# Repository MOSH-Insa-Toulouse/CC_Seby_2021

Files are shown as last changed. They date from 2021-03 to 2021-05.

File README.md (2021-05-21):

# Projet Capteur Graphite

Nous vous souhaitons bonne navigation dans notre GitHub ! 

# Sommaire
<!-- TOC depthFrom:2 -->
- [Projet Capteur Graphite](#projet-capteur-graphite)
- [Sommaire](#sommaire)
  - [1. Description](#1-description)
  - [2. Configuration de l'environnement logiciel](#2-configuration-de-lenvironnement-logiciel)
    - [2.1. Arduino](#21-arduino)
      - [2.1.1. Bibliothèques](#211-bibliothèques)
    - [2.2. KICAD](#22-kicad)
    - [2.3. Application Android](#23-application-android)
      - [2.3.1. Installer l'application](#231-installer-lapplication)
      - [2.3.2. Modifier l'application](#232-modifier-lapplication)
  - [3. Améliorations Possibles](#3-améliorations-possibles)
    - [3.1. Amélioration 1 : KICAD - Taille des pistes](#31-amélioration-1--kicad---taille-des-pistes)
    - [3.2. Amélioration 2 : KICAD - Taille des pastilles](#32-amélioration-2--kicad---taille-des-pastilles)
    - [3.3. Amélioration 3 : KICAD - Place du capteur](#33-amélioration-3--kicad---place-du-capteur)
    - [3.4. Amélioration 4 : KICAD - Orientation de l'encodeur rotatoire](#34-amélioration-4--kicad---orientation-de-lencodeur-rotatoire)
    - [3.5. Amélioration 5 : Arduino & Android - Économie du buffer Bluetooth](#35-amélioration-5--arduino--android---économie-du-buffer-bluetooth)
  - [4. Remerciements](#4-remerciements)
  - [5. Informations sur les auteurs](#5-informations-sur-les-auteurs)
<!-- /TOC -->

## 1. Description 

Ce Git contient tous les fichiers requis pour le projet capteur 2021 du Génie Physique de l'INSA de Toulouse.

**Code Arduino**

- Mesure la tension de sortie du circuit transimpédance
- Envoie la mesure de la tension en Bluetooth sur 1 octet
- Calcule la résistance du capteur grâce à l'équation de transfert du circuit dans la data sheet
- Affiche les mesures sur un écran oled 128x32
- Gère l'encodeur rotatoire pour interagir avec un menu sur l'écran oled

**KICAD**

Projet complet de design de shield pour Arduino Uno :

- Interface un module Bluetooth
- Interface un écran oled
- Interface notre capteur graphite via un circuit transimpédance
- Interface un encodeur rotatoire

**Application Android**

- Récupère la mesure de tension en binaire sur 1 octet
- Affiche la valeur de la tension en Volt
- Calcule la résistance du capteur grâce à l'équation de transfert du circuit dans la data sheet
- Affiche la valeur de la résistance MΩ
- Trace un graphique déroulant de la résistance du capteur
- Mise à l'échelle du graphique grâce à un slider

**Data Sheet**

- Caractéristiques principales
- Description du capteur 
- Schéma et dimensions 
- Spécifications
- Conditions d'utilisation normales
- Caractéristiques électriques
- Caractéristiques de déformation
- Montage typique d'utilisation

## 2. Configuration de l'environnement logiciel

### 2.1. Arduino

Lien pour installer l'IDE Arduino sur sa machine : https://www.arduino.cc/en/software

#### 2.1.1. Bibliothèques

À installer depuis l'IDE ou GitHub : 
- Adafruit GFX Library : https://github.com/adafruit/Adafruit-GFX-Library
- Adafruit SSD1306 : https://github.com/adafruit/Adafruit_SSD1306
- Adafruit BusIO : https://github.com/adafruit/Adafruit_BusIO

Comment installer une bibliothèque Arduino ? : https://www.arduino.cc/en/Guide/Libraries#how-to-install-a-library

### 2.2. KICAD

Lien pour installer KICAD sur sa machine : https://www.kicad.org/

### 2.3. Application Android

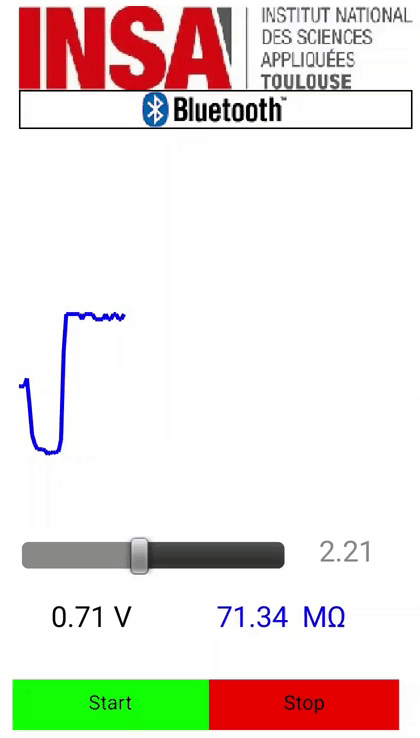
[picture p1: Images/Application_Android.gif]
Application Android


#### 2.3.1. Installer l'application

Lien pour installer un fichier .apk à partir d'un PC : https://fr.wikihow.com/installer-sur-un-Android-des-fichiers-APK-%C3%A0-partir-d%E2%80%99un-PC

#### 2.3.2. Modifier l'application

Pour modifier le code de l'application Android, vous pouvez utiliser le fichier en .aia dans MIT Inventor : https://appinventor.mit.edu/

## 3. Améliorations Possibles

### 3.1. Amélioration 1 : KICAD - Taille des pistes

À l'INSA Toulouse, la méthode d'impression du Shield par photolithographie avec du matériel rudimentaire a engendré de nombreux court-circuits entre les pistes de la plaque. Il peut-être judicieux d'augmenter la taille des pistes du PCB dans KICAD selon le matériel. **À l'INSA 0.8mm sont recommandés**

**Comment modifier la taille des pistes ?**

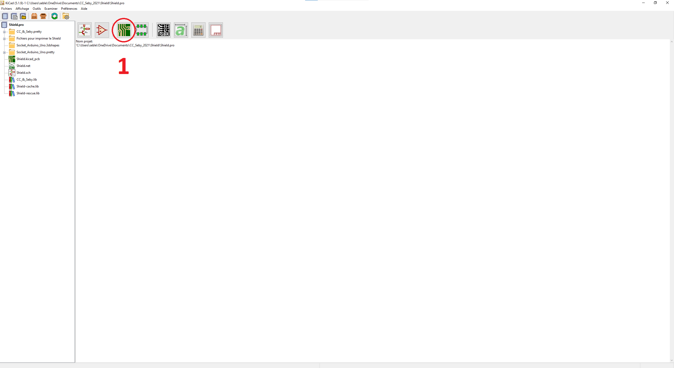
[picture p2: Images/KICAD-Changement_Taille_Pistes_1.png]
Étape 1

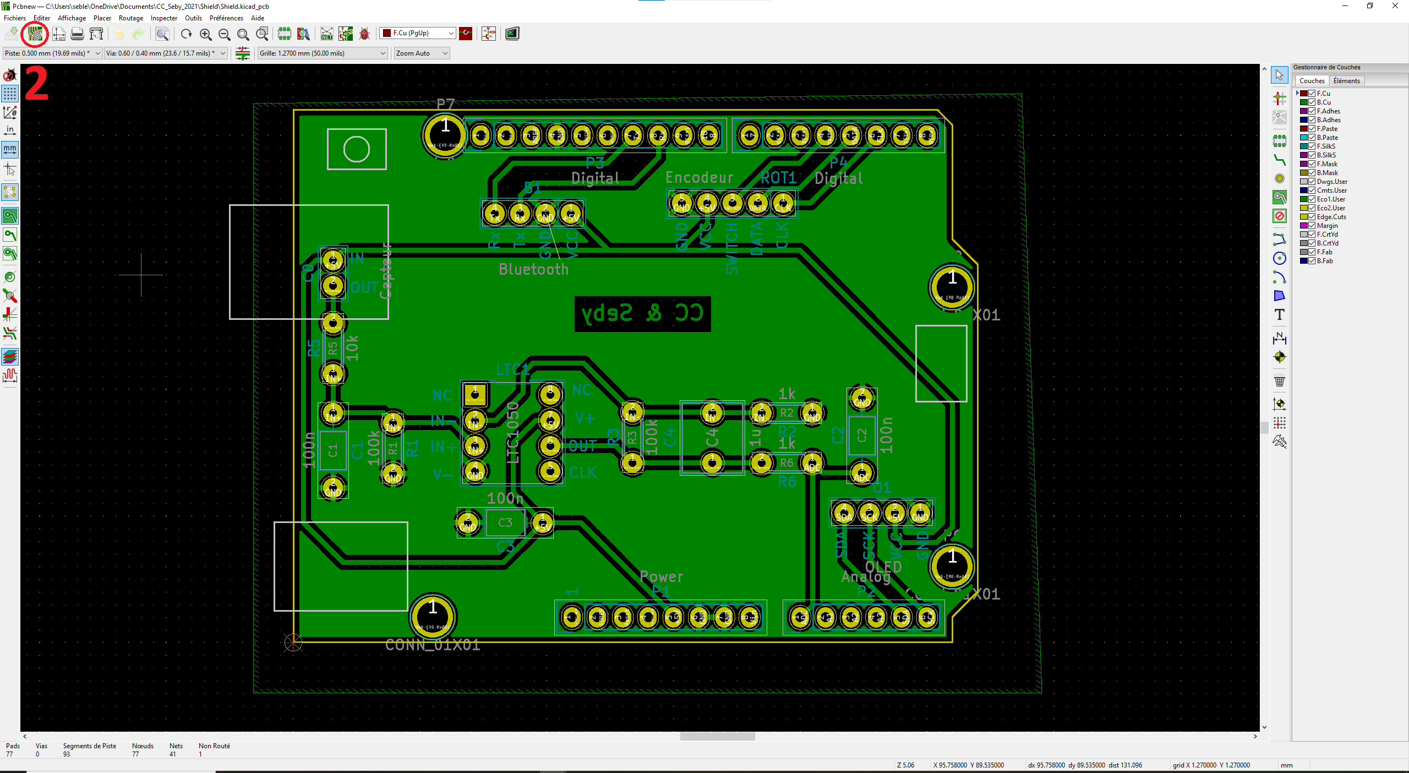
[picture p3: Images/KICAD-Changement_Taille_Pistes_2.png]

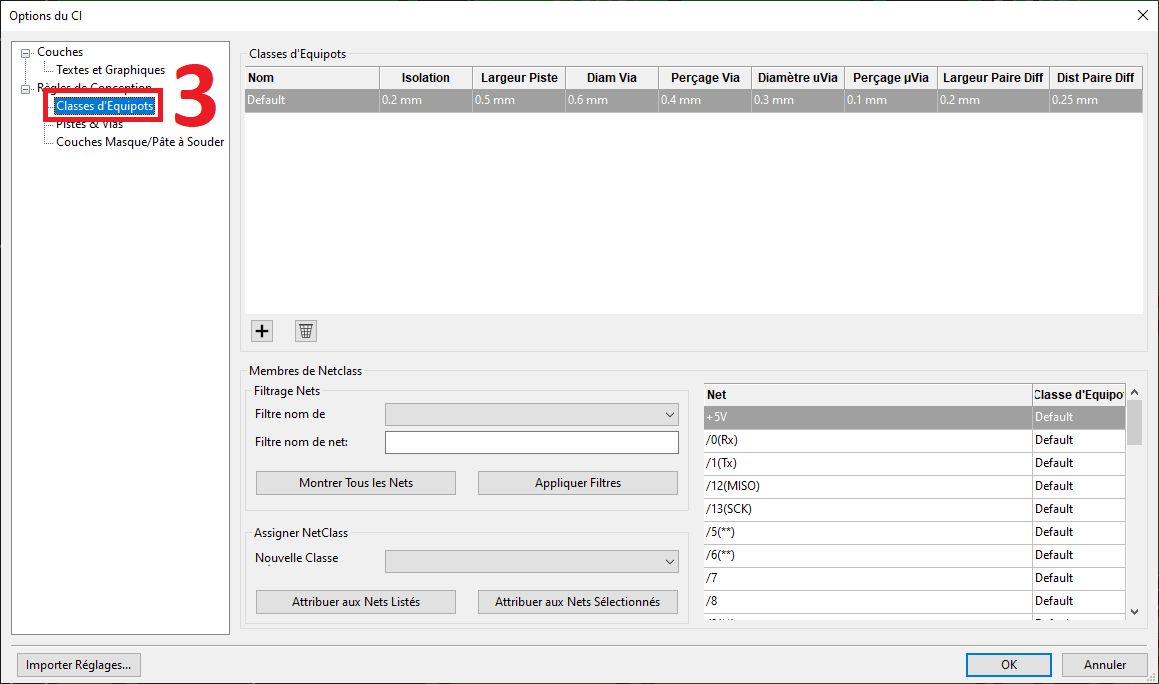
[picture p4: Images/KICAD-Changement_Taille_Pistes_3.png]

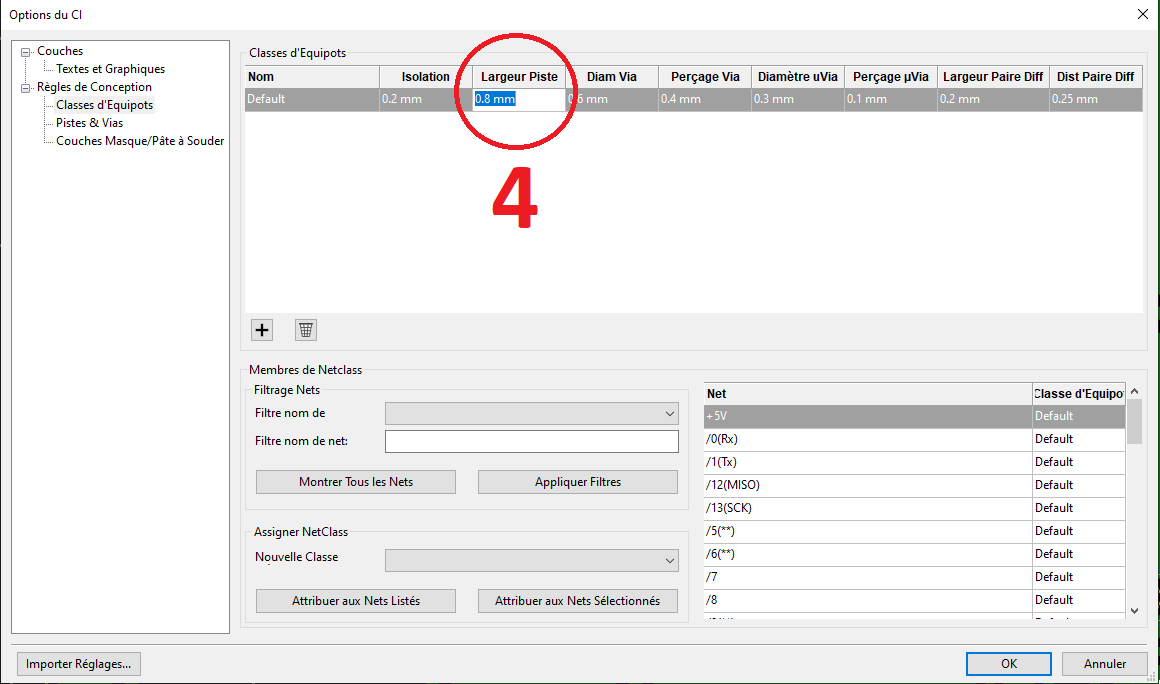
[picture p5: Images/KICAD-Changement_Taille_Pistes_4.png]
Étape 4


Il faut ensuite supprimer les pistes et refaire le routage de la carte.

### 3.2. Amélioration 2 : KICAD - Taille des pastilles

À l'INSA Toulouse, le foret de la perceuse a un diamètre de 0.8mm, il faut donc prévoir un **perçage supérieur ou égal à 0.8mm**.

Étape 1
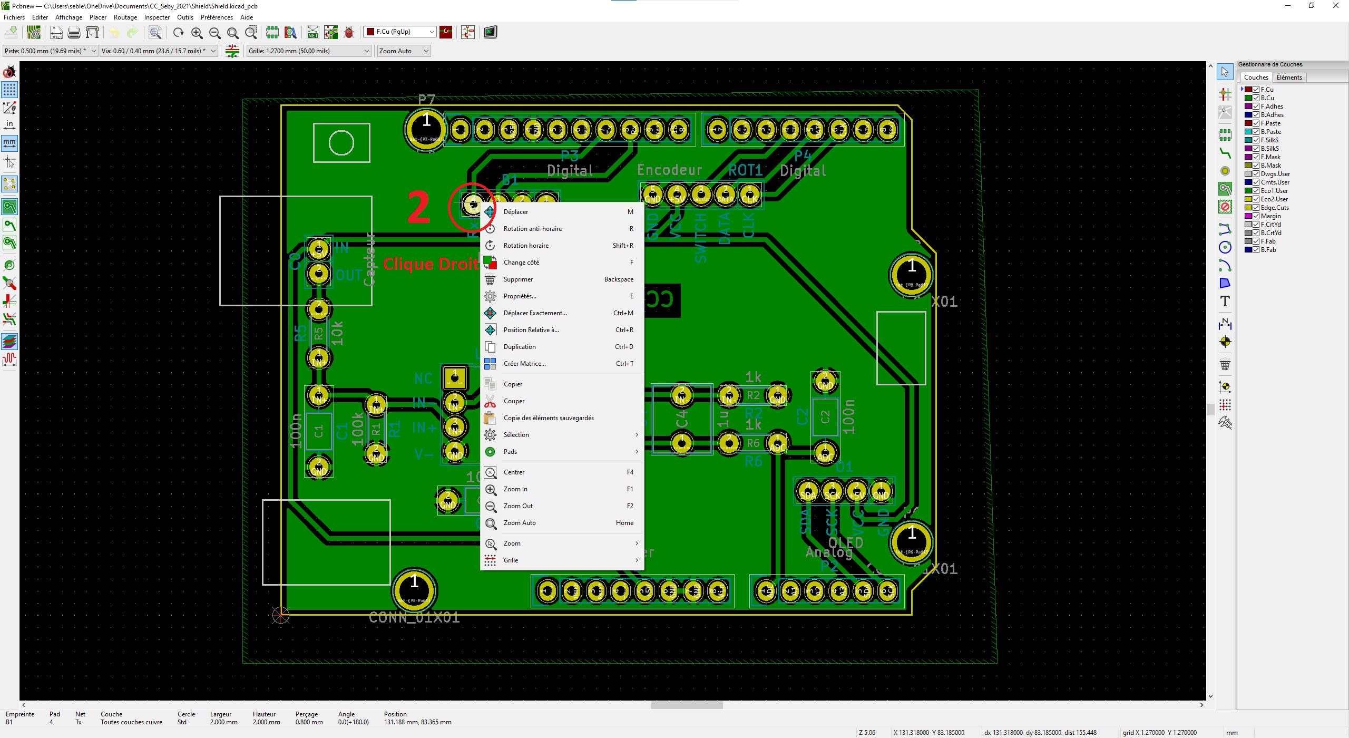
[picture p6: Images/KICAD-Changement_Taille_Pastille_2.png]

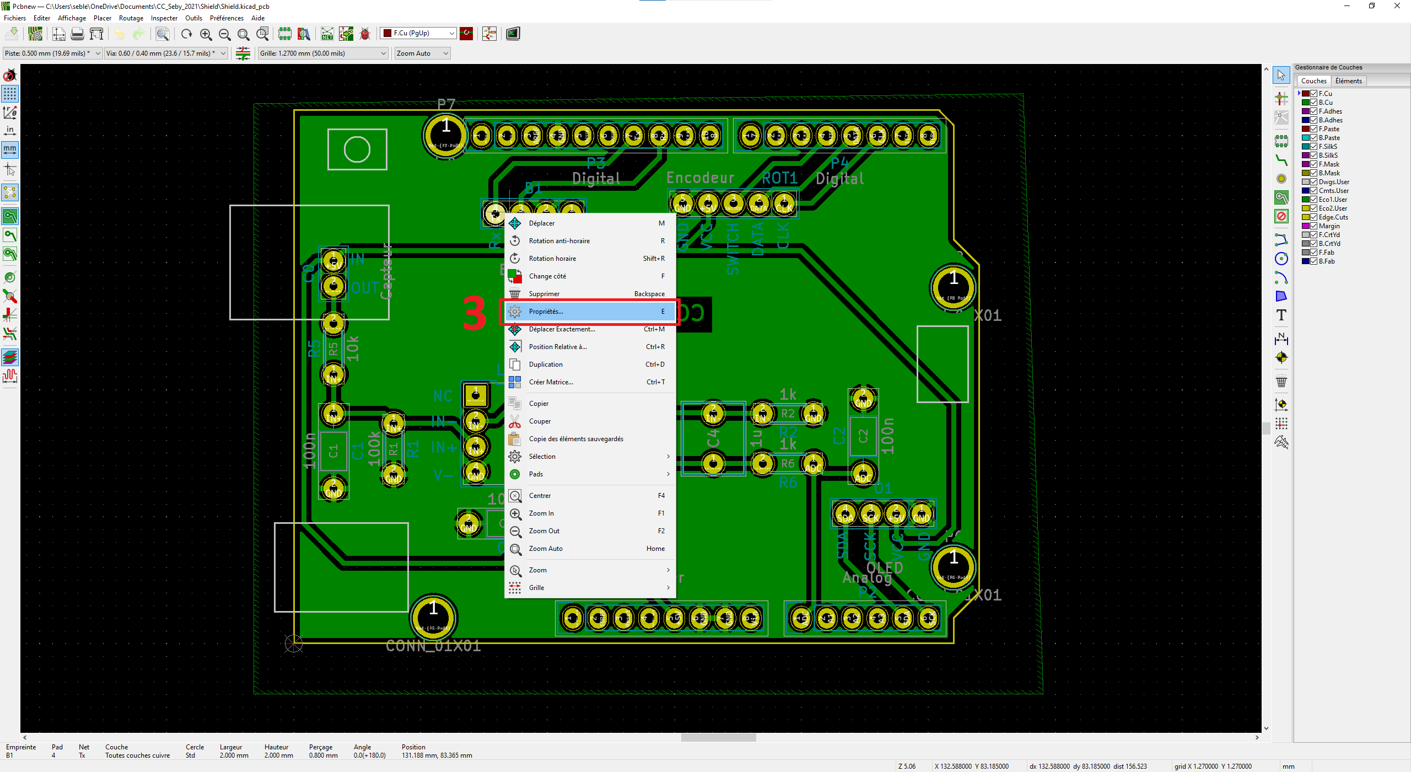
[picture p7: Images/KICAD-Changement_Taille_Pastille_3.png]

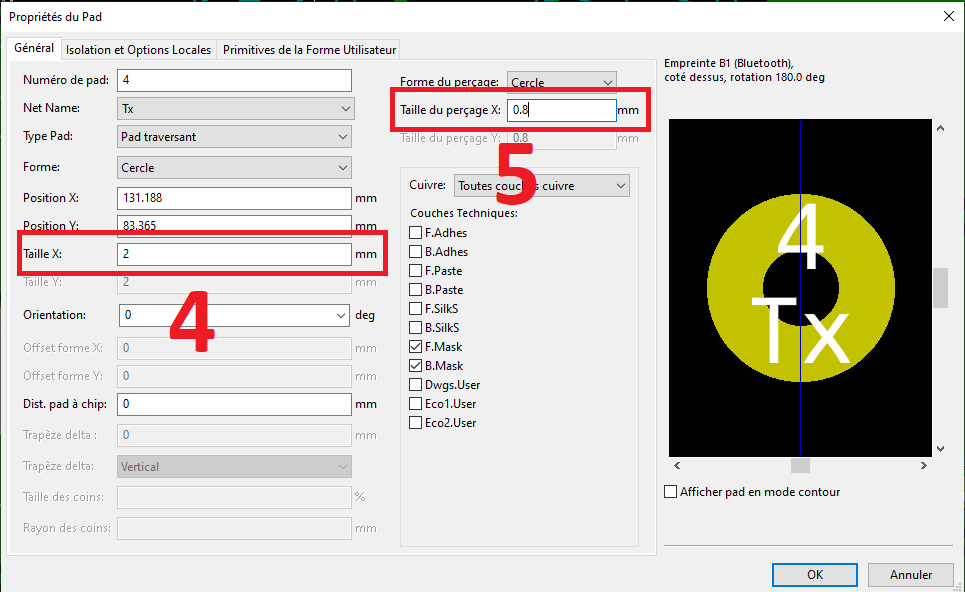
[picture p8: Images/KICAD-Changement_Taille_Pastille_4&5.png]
Étape 4&5


### 3.3. Amélioration 3 : KICAD - Place du capteur

**Description du problème**

Les pins de connexion fournis du shield à l'Arduino étant un peu courts. Les soudures des connexions du capteur sont en contact avec le boitier de blindage de l'USB qui est à la masse. Nous avons rajouté une feuille de papier entre le Shield et l'Arduino afin d'assurer l'isolation. Un changement de design du Shield serait donc judicieux avant toute nouvelle impression.

**Solution Proposée**

Étape 1
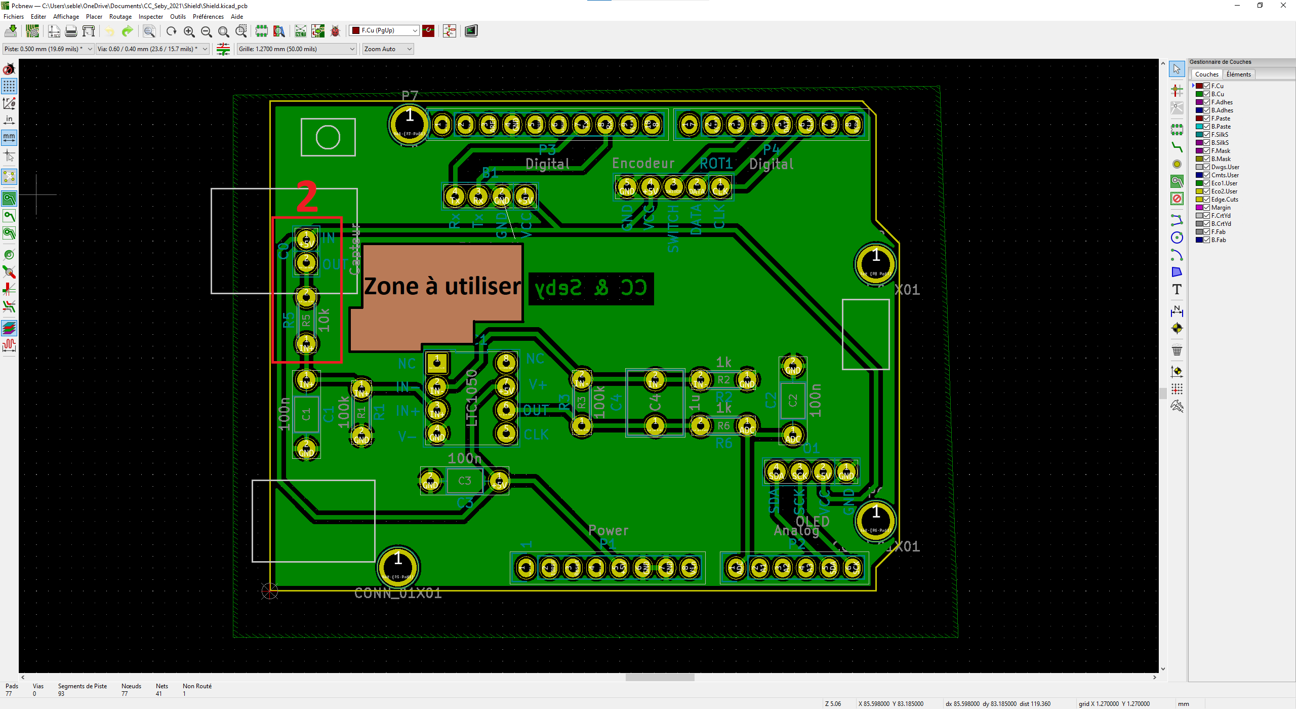
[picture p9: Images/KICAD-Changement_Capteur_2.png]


### 3.4. Amélioration 4 : KICAD - Orientation de l'encodeur rotatoire

**Description du problème**

Le bouton poussoir de l'encodeur rotatoire est actuellement orienté vers l'intérieur du shield. La manipulation pourrait être améliorée en orientant l'encodeur vers l'extérieur du shield.

**Solution proposée**

Étape 1
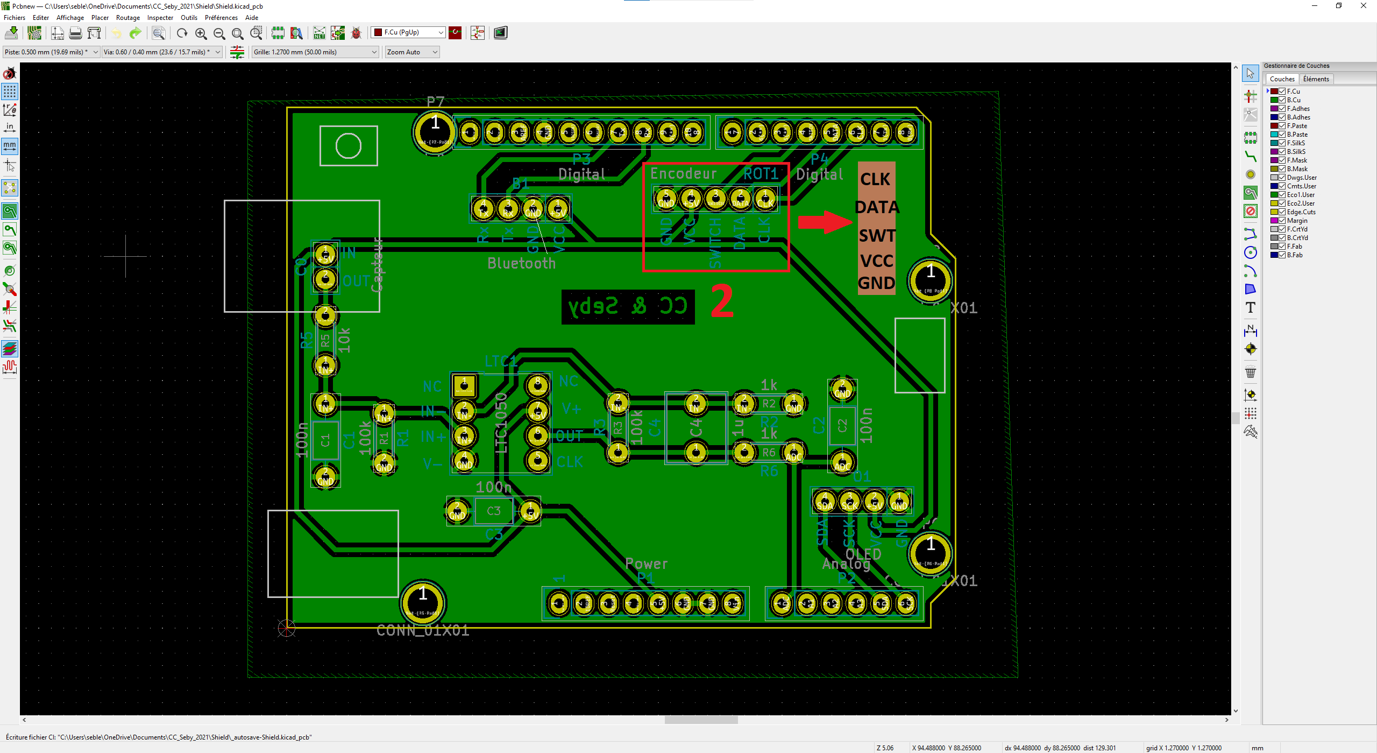
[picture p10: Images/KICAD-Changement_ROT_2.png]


### 3.5. Amélioration 5 : Arduino & Android - Économie du buffer Bluetooth

**Description**

Actuellement, la carte Arduino envoie continuellement les mesures de tension dans le buffer du Bluetooth peu importe qu'un appareil soit connecté ou pas. Le buffer du dongle Bluetooth est alors rempli de vieilles mesures qui seront quand même lues lorsqu'un appareil se mettra à lire les données.

**Solution Proposée**

_Arduino_

- Création d'une variable Mode_Bluetooth de type entier 
- Création d'une procédure de modification de Mode_Bluetooth lors de la réception de strings particuliers en Bluetooth
- Ajout d'un bloc If Mode_Bluetooth qui conditionne l'envoi des mesures en Bluetooth

_Android_

- Envoi d'un string en Bluetooth (ex : "ON") lorsqu'on démarre le timer de mesure
- Envoi d'un string en Bluetooth (ex : "OFF") lorsqu'on arrête le timer de mesure

## 4. Remerciements

Nous tenons à remercier toutes les personnes qui nous ont aidé tout au long de ce projet !

## 5. Informations sur les auteurs

**Séléna PONDARD**

Étudiante en 4ème année du Génie Physique de l'INSA de Toulouse

Mail : pondard@etud.insa-toulouse.fr

**Sébastien LENI**

Étudiant en 4ème année du Génie Physique de l'INSA de Toulouse

Mail : leni@etud.insa-toulouse.fr

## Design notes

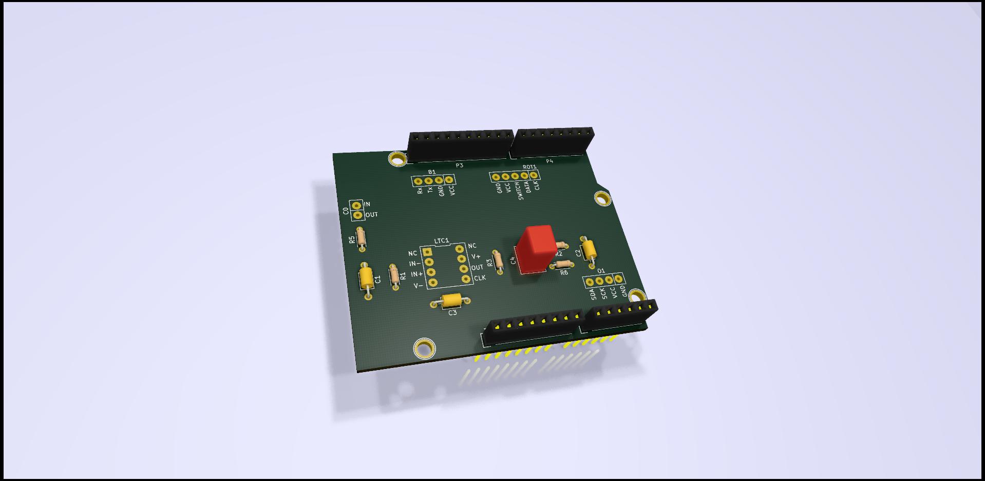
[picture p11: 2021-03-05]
Shield/Fichiers pour imprimer le Shield/PONDARD_LENI - Vue 3D.jpg

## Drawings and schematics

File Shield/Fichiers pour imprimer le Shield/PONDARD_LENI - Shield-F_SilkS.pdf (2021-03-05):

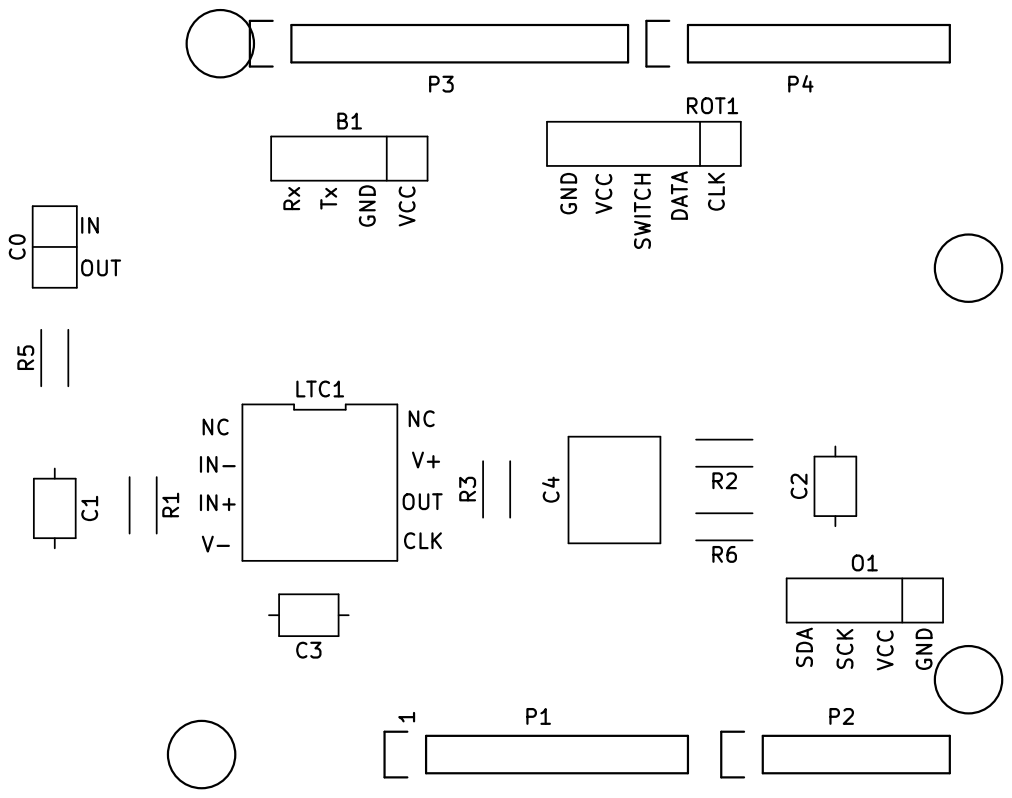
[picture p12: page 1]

1 C3 ROT1 GND VCC SWITCH DATA CLK

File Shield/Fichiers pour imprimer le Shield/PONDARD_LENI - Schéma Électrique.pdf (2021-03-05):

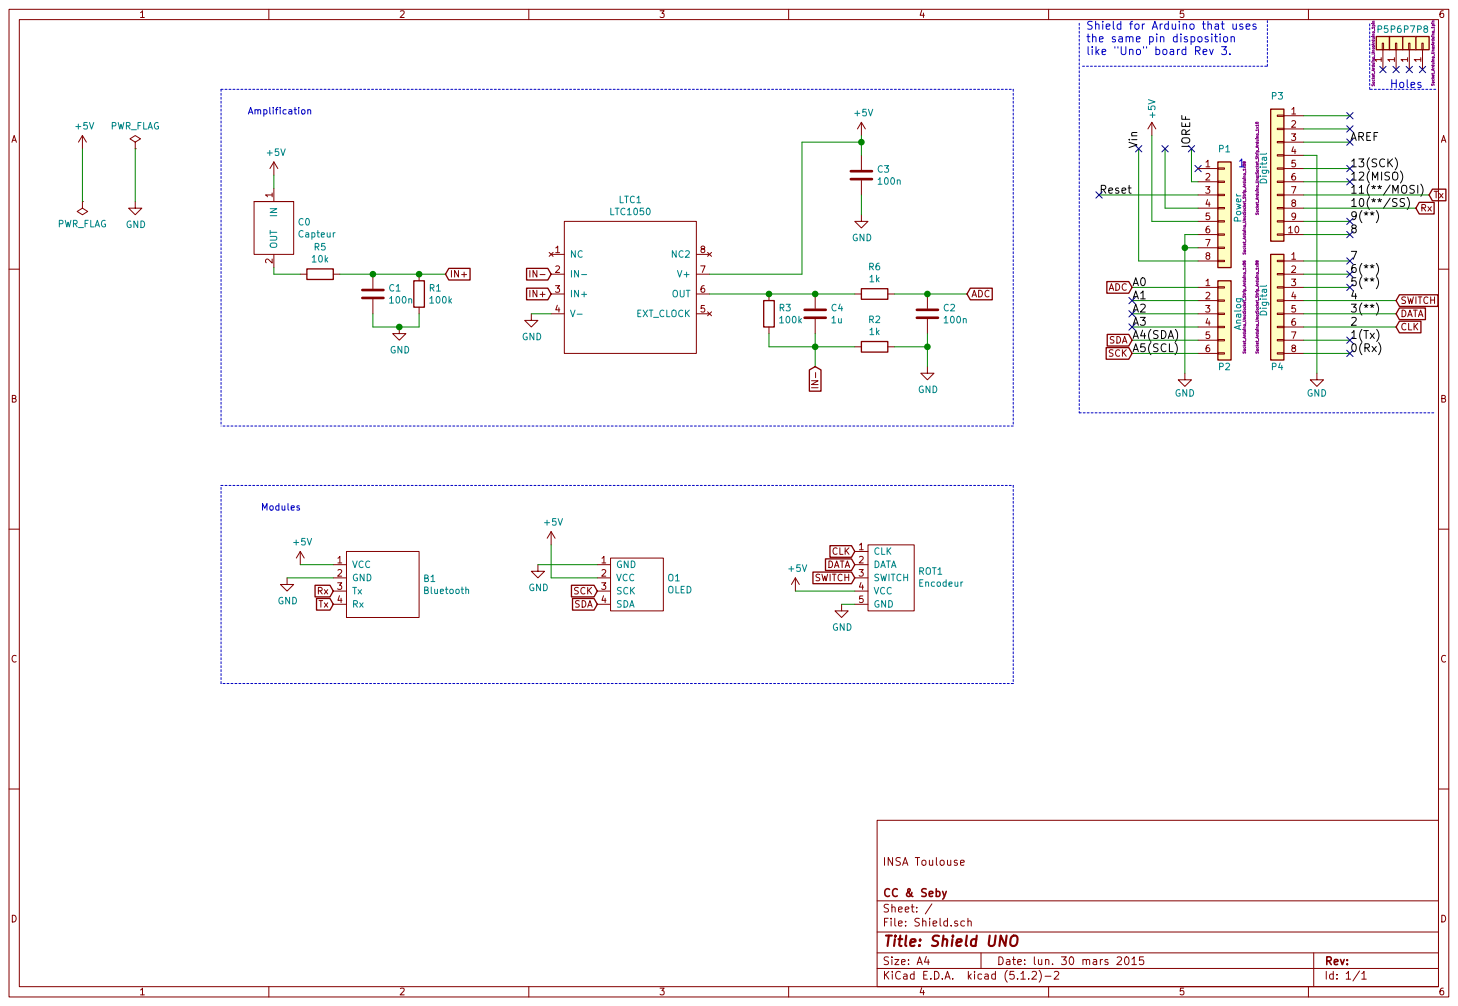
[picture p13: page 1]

the same pin disposition
like "Uno" board Rev 3. 1

2 C0Capteur CLK 1 DATA 2 SWITCH 3 VCC 4 GND 5 ROT1 Encodeur CLK DATA

File: Shield.sch Sheet: / CC & Seby

Id: 1/1 Title: Shield UNO

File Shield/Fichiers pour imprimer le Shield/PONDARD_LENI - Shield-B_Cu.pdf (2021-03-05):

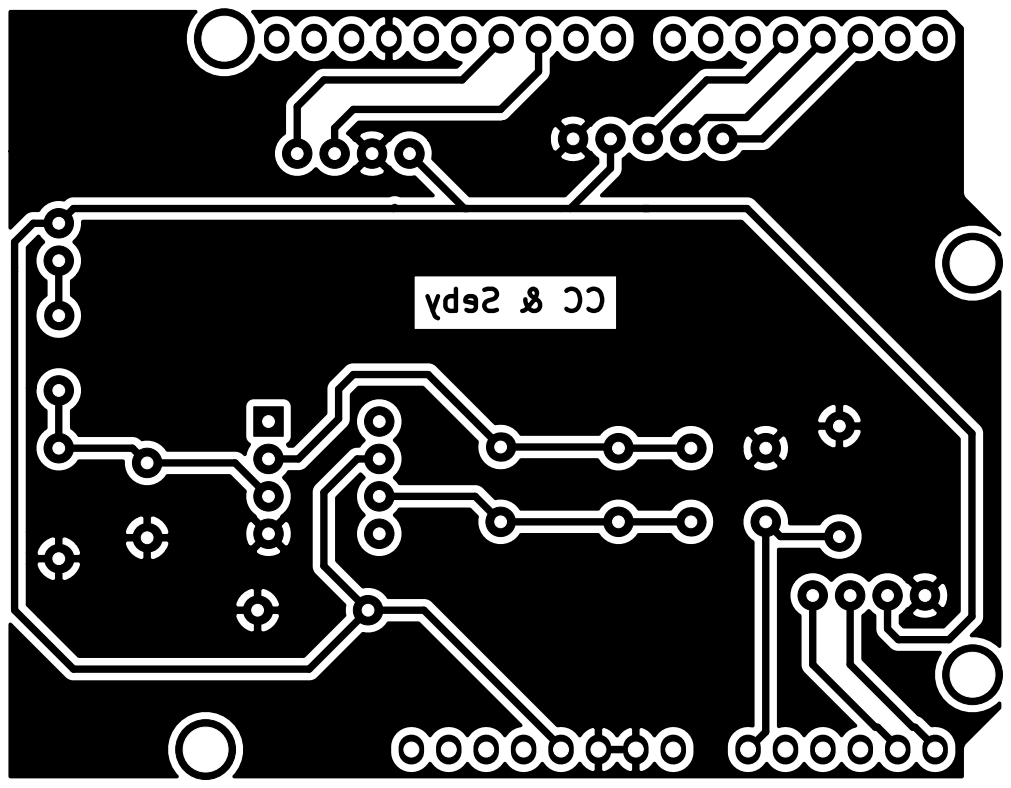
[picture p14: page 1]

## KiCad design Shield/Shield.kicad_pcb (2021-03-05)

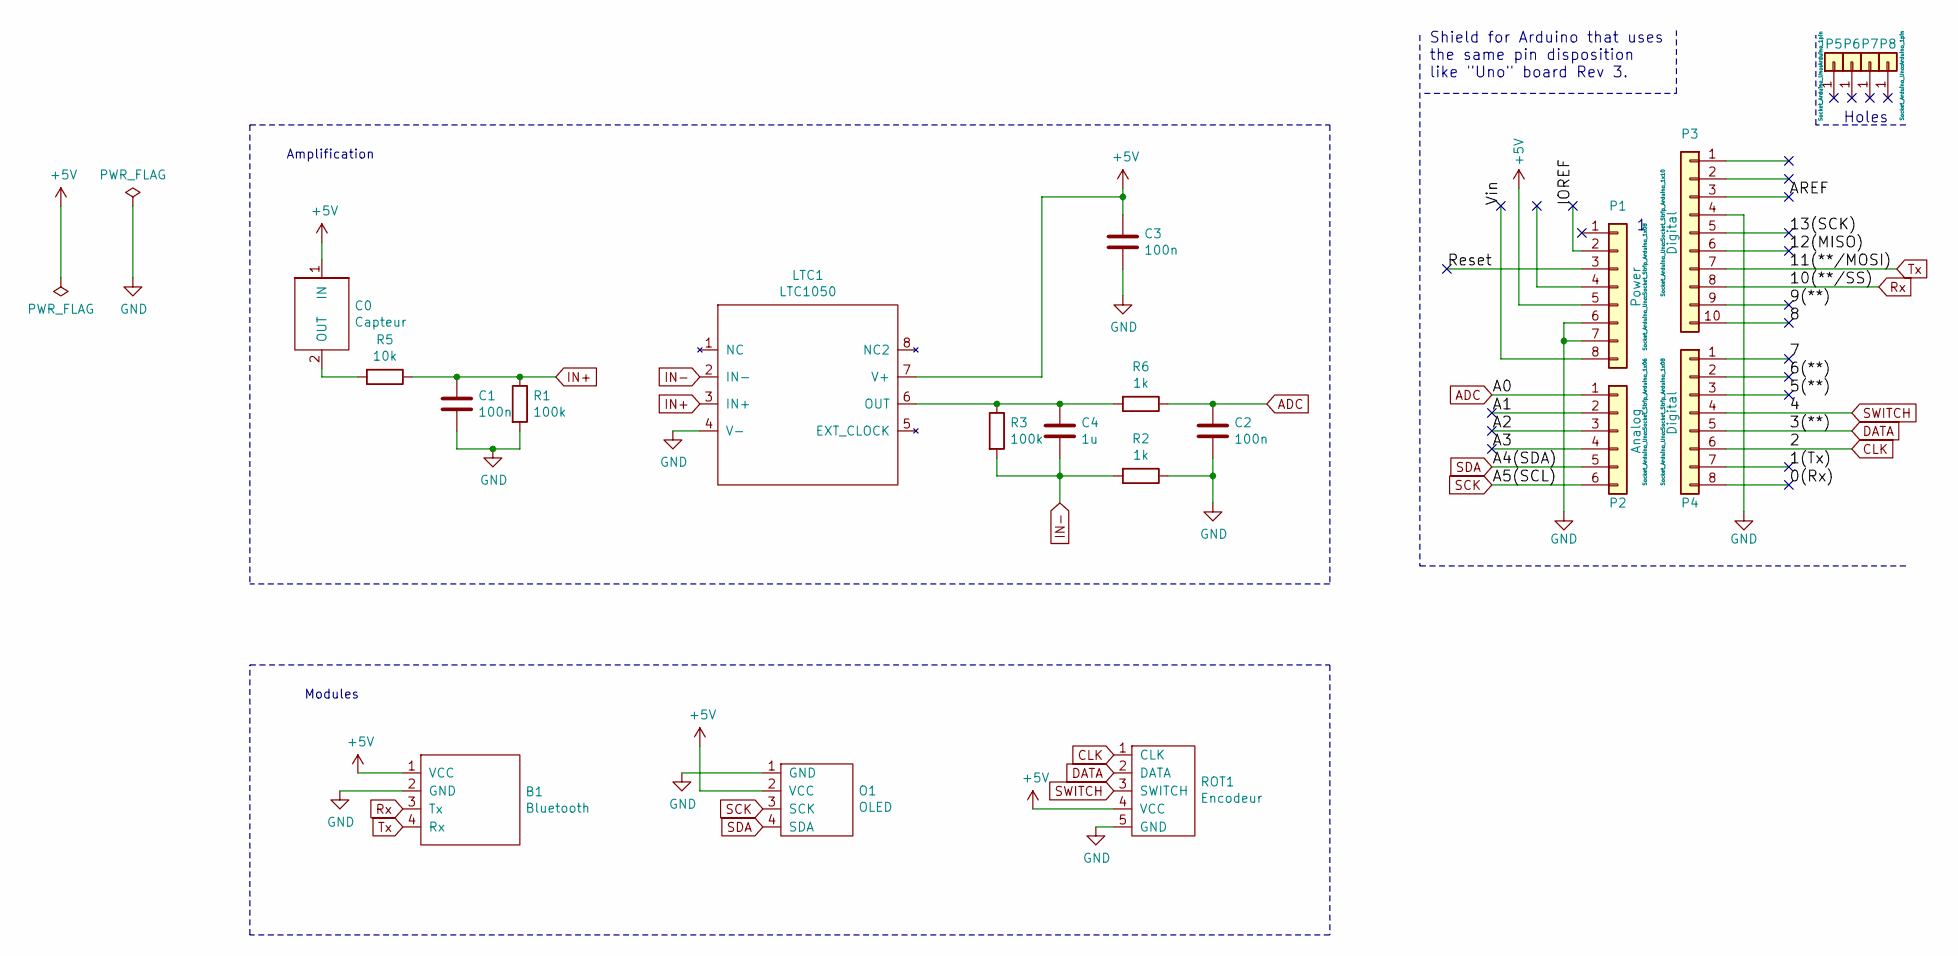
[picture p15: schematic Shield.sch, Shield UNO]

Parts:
B1: Bluetooth
C0: Capteur
C1, C2, C3: 100n; C_Axial_L3.8mm_D2.6mm_P7.50mm_Horizontal
C4: 1u; C_Rect_L7.0mm_W6.0mm_P5.00mm
LTC1: LTC1050
O1: OLED
P1: Power; Socket_Strip_Arduino_1x08
P2: Analog; Socket_Strip_Arduino_1x06
P3: Digital; Socket_Strip_Arduino_1x10
P4: Digital; Socket_Strip_Arduino_1x08
P5, P6, P7, P8: CONN_01X01; Arduino_1pin
R1, R3: 100k; R_Axial_DIN0204_L3.6mm_D1.6mm_P5.08mm_Horizontal
R2, R6: 1k; R_Axial_DIN0204_L3.6mm_D1.6mm_P5.08mm_Horizontal
R5: 10k; R_Axial_DIN0204_L3.6mm_D1.6mm_P5.08mm_Horizontal
ROT1: Encodeur

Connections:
+5V: B1.1 (VCC), C0.1 (IN), C3.1, LTC1.7 (V+), O1.2 (VCC), P1.5, ROT1.4 (VCC)
/0(Rx): P4.8
/1(Tx): P4.7
/5(**): P4.3
/6(**): P4.2
/7: P4.1
/8: P3.10
/9(**): P3.9
/12(MISO): P3.6
/13(SCK): P3.5
/A1: P2.2
/A2: P2.3
/A3: P2.4
/AREF: P3.3
/IOREF: P1.2
/Reset: P1.3
/Vin: P1.8
ADC: C2.1, P2.1, R6.1
CLK: P4.6, ROT1.1 (CLK)
DATA: P4.5, ROT1.2 (DATA)
GND: B1.2 (GND), C1.2, C2.2, C3.2, LTC1.4 (V-), O1.1 (GND), P1.6, P1.7, P3.4, R1.2, R2.1, ROT1.5 (GND)
IN+: C1.1, LTC1.3 (IN+), R1.1, R5.1
IN-: C4.2, LTC1.2 (IN-), R2.2, R3.2
unnamed: C0.2 (OUT), R5.2
unnamed: C4.1, LTC1.6 (OUT), R3.1, R6.2
Rx: B1.3 (Tx), P3.8
SCK: O1.3 (SCK), P2.6
SDA: O1.4 (SDA), P2.5
SWITCH: P4.4, ROT1.3 (SWITCH)
Tx: B1.4 (Rx), P3.7

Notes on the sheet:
Holes
Shield for Arduino that uses the same pin disposition like "Uno" board Rev 3.
Amplification
Modules

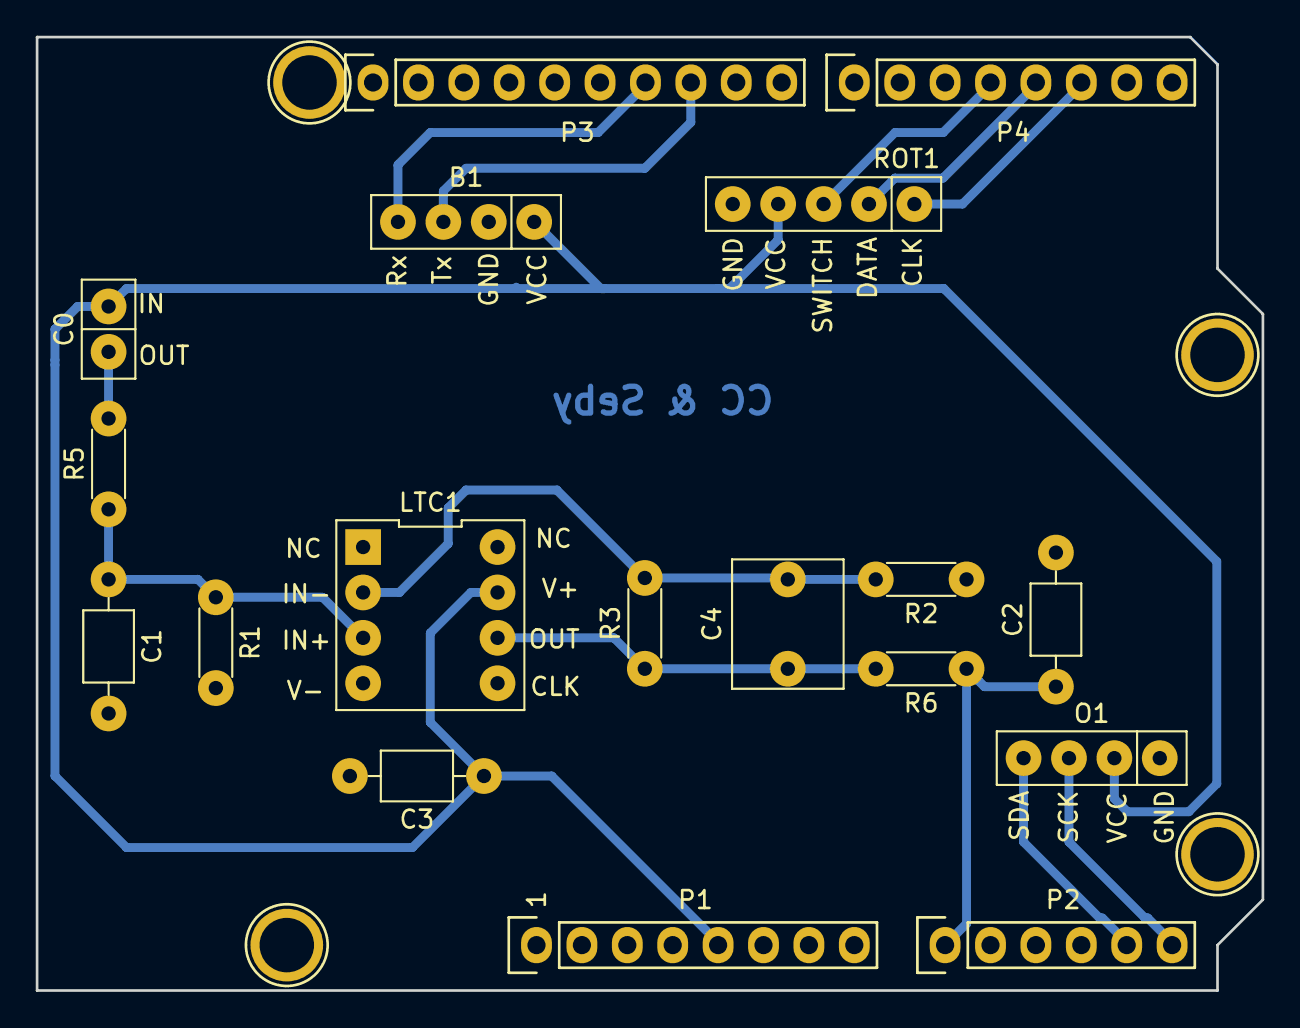
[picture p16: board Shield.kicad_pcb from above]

Board: 2 copper layers, 68.6 x 53.3 mm, 22 parts (0 on the bottom side), 14 nets.

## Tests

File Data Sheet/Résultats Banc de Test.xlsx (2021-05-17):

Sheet: B
Épaisseur du papier (m) | Rayon de Courbure (m) | Déformation | Résistance B (Mohms) | Résistance B/R0 | ∆R (Mohms) | ∆R/R0
0.0003 | 1.79e+307 | 0% | 19 | 1 | 0 | 0%
 | 0.025 | 0.5964214712% | 19.7 | 1.036842105 | 0.7 | 3.684210526%
 | 0.025 | -0.5964214712% | 18.5 | 0.9736842105 | -0.5 | -2.631578947%
 | 0.01 | 1.477832512% | 21.2 | 1.115789474 | 2.2 | 11.57894737%
 | 0.01 | -1.477832512% | 17 | 0.8947368421 | -2 | -10.52631579%
 | 0.0175 | 0.8498583569% | 19.9 | 1.047368421 | 0.9 | 4.736842105%
 | 0.0175 | -0.8498583569% | 17.5 | 0.9210526316 | -1.5 | -7.894736842%
 | 0.0225 | 0.6622516556% | 19.7 | 1.036842105 | 0.7 | 3.684210526%
 | 0.0225 | -0.6622516556% | 18.3 | 0.9631578947 | -0.7 | -3.684210526%
 | Min | Max
 | 18.8 | 19.5
 | 21.3 | 21.6
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

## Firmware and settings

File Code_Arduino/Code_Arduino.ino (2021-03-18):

/**********************************
********** Bibliothèques **********
**********************************/  
 
#include <SoftwareSerial.h>
#include <SPI.h>
#include <Wire.h>
#include <Adafruit_GFX.h>
#include <Adafruit_SSD1306.h>

/**********************************
****** Définition des Ports *******
**********************************/

#define baudrate 9600

//Module Bluetooth
#define rxPin 11
#define txPin 10
SoftwareSerial Bluetooth(rxPin,txPin);

//Capteur
#define analog_port 0

//Écran 
//Arduino UNO : A4(SDA), A5(SCL)
#define SCREEN_ADDRESS 0x3C
Adafruit_SSD1306 display(-1);  //-1 car pas de pin reset

//Encodeur rotatoir
#define CLK 2      //CLK Output A
#define DATA 3     //DT Output B
#define Switch 4   //Switch connection

/**********************************
****** Variables Globales  *******
**********************************/

float tension;
double resistance;

//Variables de l'encodeur
volatile unsigned int Selector = 0;
//0 Resistance
//1 Tension

volatile unsigned int Menu = 0;
//0  mesure on 
//1  mesure off, menu

bool swState  = HIGH;
bool swLast  = LOW;

/**********************************
*********** Fonctions *************
**********************************/

void Affichage_Tension (double u) 
{
  //Configuration de l'écran
  display.clearDisplay();
  display.setTextSize(2); 
  display.setTextColor(WHITE);

  //Affichage de la tension
  Serial.println(u);
  display.setCursor(30, 0);
  display.println(F("Tension"));
  display.setCursor(40, 17);
  display.println(u);
  display.setCursor(90, 17);
  display.println(F("V"));
  display.display();
}

void Affichage_Resistance (double r) 
{
  //Configuration de l'écran
  display.clearDisplay();
  display.setTextSize(2); 
  display.setTextColor(WHITE);

  //Affichage de la résistance
  Serial.println(r);
  display.setCursor(5, 0);
  display.println(F("Resistance"));
  display.setCursor(0, 17);
  display.println(r,1);
  display.setCursor(65, 17);
  display.println(F("MOhms"));
  display.display();
}

void Menu_OLED()
{
  if (Selector == 0)
  {
    Selector = 1;
  }
  else 
  {
    Selector = 0;
  }
}

/**********************************
****** Programme Principal ********
**********************************/

void setup()
{

 
 //Configuration des ports du bluetooth
 pinMode(rxPin,INPUT);
 pinMode(txPin,OUTPUT);

 //Configuration des ports de l'encodeur rotatoir
 pinMode(CLK,INPUT);
 digitalWrite(CLK,HIGH);
 pinMode(DATA,INPUT);
 digitalWrite(DATA,HIGH);

 //Ouverture des ports
 Bluetooth.begin(baudrate);
 Serial.begin(baudrate);
 display.begin(SSD1306_SWITCHCAPVCC, SCREEN_ADDRESS);
 
 //Écran de démarrage
 display.clearDisplay();
 display.setTextSize(2); 
 display.setTextColor(WHITE);
 display.setCursor(5, 10);
 display.println(F("CC et Seby"));
 display.display();
 delay(2000);

}

void loop() 
{

  //Mesures
  tension = analogRead(analog_port);

  //Envoie des données par Bluetooth
  byte V = map(tension,0,1023,0,255);
  Bluetooth.write(V);

  tension = tension*5/1024;
  resistance = (1.0+100.0)*100000.0*(5.0/tension)-100000.0-10000.0;

  delay(250);

  //Gestion du bouton de l'encodeur rotatoir
  swState = digitalRead(Switch);
  if (swState == HIGH && swLast == LOW && Menu ==0) 
  {
    Menu=1;
    attachInterrupt(digitalPinToInterrupt(DATA), Menu_OLED, RISING);
    delay(500);//debounce 
  }
  else if (swState == HIGH && swLast == LOW && Menu ==1) 
  {
    Menu=0;
    detachInterrupt(digitalPinToInterrupt(DATA)); 
    delay(500);//debounce
  }
  swLast = swState;

  //Gestion de l'Affichage sur l'écran OLED
  switch (Menu)
  {
    case 0 :
      switch (Selector)
    {
      case 0 : 
      Affichage_Resistance(resistance/1000000.0);
      break;
  
      case 1 :
      Affichage_Tension (tension) ;
      break;
    }
    break;
    
    case 1 :
      switch (Selector)
    {
      case 0 : 
      //Configuration de l'écran
      display.clearDisplay();
      display.setTextSize(1); 
      display.setTextColor(WHITE);
  
      display.setCursor(5, 0);
      display.println(F(" -> Resistance"));
      display.setCursor(30, 17);
      display.println(F("Tension"));
      display.display();
      break;
  
      case 1 :
      //Configuration de l'écran
      display.clearDisplay();
      display.setTextSize(1); 
      display.setTextColor(WHITE);
  
      display.setCursor(30, 0);
      display.println(F("Resistance"));
      display.setCursor(5, 17);
      display.println(F(" -> Tension"));
      display.display();
      break;
    }
    break;
  } 
}

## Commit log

2021-02-23 Code Arduino V0
2021-03-05 ARDUINO V2
    [Shield.kicad_pcb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]
2021-03-08 Arduino MAJ
2021-03-10 modification Arduino
2021-03-24 Fichier pour impression
    [PONDARD_LENI - Shield-B_Cu.gbr, PONDARD_LENI - Shield-F_SilkS.gbr]
2021-03-25 banc de test
    [Résultats Banc de Test (Jordi ROUBICHOU et Mathias SOULIER).xlsx]
2021-03-25 Readme du futur
    [Résultats Banc de Test (Jordi ROUBICHOU et Mathias SOULIER).xlsx]
2021-03-25 j'en ai marre
    [Résultats Banc de Test (Jordi ROUBICHOU et Mathias SOULIER).xlsx, Résultats Banc de Test.xlsx]
2021-03-26 Ptn de démo
    [Résultats Banc de Test (Jordi ROUBICHOU et Mathias SOULIER).xlsx]
2021-03-27 correction graphique
    [Résultats Banc de Test (Jordi ROUBICHOU et Mathias SOULIER).xlsx, Résultats Banc de Test.xlsx]
2021-04-09 ca sent la fin
2021-04-09 Ca sent la fin pour de vrai
    [Résultats Banc de Test (Jordi ROUBICHOU et Mathias SOULIER).xlsx]
2021-05-05 Et ça repart
    [Résultats Banc de Test.xlsx]
2021-05-17 on est de retour
    [Résultats Banc de Test.xlsx]
